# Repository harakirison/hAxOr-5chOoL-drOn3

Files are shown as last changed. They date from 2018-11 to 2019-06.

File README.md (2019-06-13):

# hAxOr-5chOoL-drOn3
Hacker School Drone 11/2018

ESP8266-12e als RX:

https://www.instructables.com/id/Wifi-PPM-no-App-Needed/

https://www.mikrocontroller-elektronik.de/esp12e-tutorial-einstieg-mit-dem-esp8266-modul/

### Propeller

* https://www.youtube.com/watch?v=CKGabWs2Ih0

### Useful-Links:
* https://www.youtube.com/watch?v=J66_8P043ko
* https://www.youtube.com/watch?v=8Dr_GhXI85I&t=0s
* https://www.youtube.com/watch?v=Mlgi6CB7WXQ
#### for flashing the FC:
* https://www.youtube.com/watch?v=Krv-CMSfb_M
* https://www.youtube.com/watch?v=cCgrKOVxnWQ
* https://www.youtube.com/watch?v=-fK6NnnAzuo

### Parts:

#### Flight Controller
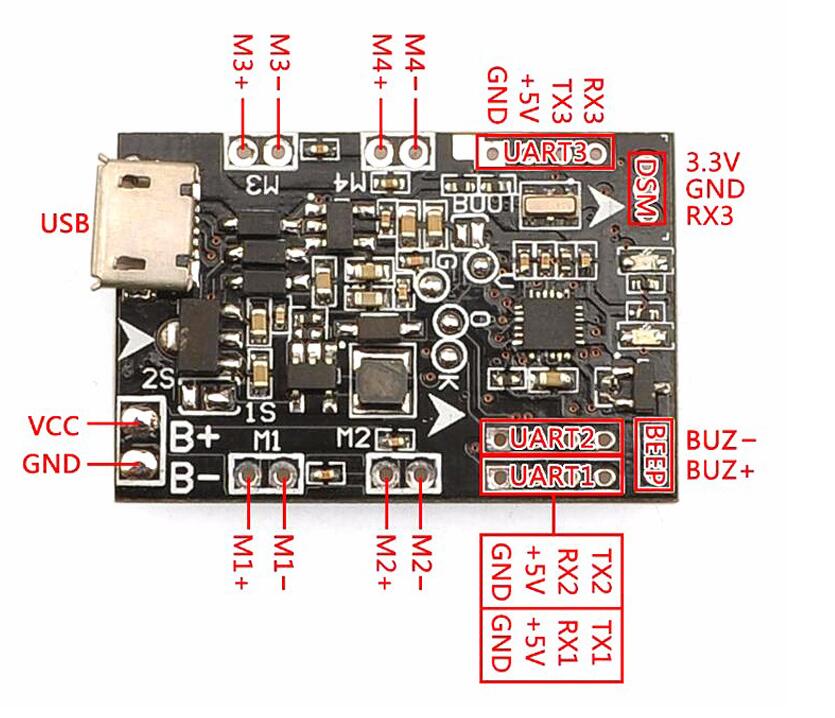
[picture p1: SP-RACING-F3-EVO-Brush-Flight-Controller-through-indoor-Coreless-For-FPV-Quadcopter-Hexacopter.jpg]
Flight Controller

* https://www.ebay.de/itm/F18730-SP-RACING-F3-EVO-Flugsteuerung-durch-Indoor-Coreless/152819911419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

#### Motors:
* https://de.aliexpress.com/item/10PCS-716-Coreless-Motor-Magnetic-Mini-HM-Motor-For-Helicopter-Airplane-Robotic/32793657274.html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
* https://de.aliexpress.com/item/10PCS-LOT-NdFeB-Super-Magnetic-8520-Hollow-Cup-Motor-3V-45000-RPM-Quadcopter-Model-Aircraft-Motor/32829046922.html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

#### Props:
* https://de.aliexpress.com/item/Accessories-For-Quadcopter-Propellers-Props-for-Eachine-E010-JJRC-H36-Blade-Inductrix-Tiny-Whoop-Drone-Part/32822191271.html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
* https://de.aliexpress.com/item/4-8-20-40-st-cke-49mm-4-9-cm-Requisiten-Mini-Propeller-Blades-Props-F/32922298325.html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
* https://de.aliexpress.com/item/Wholesale-65mm-Propeller-Prop-Blade-For-720-8520-Coreless-Motor-DIY-Micro-Quadcopter-spare-parts-40pcs/32799845267.html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
* https://de.aliexpress.com/item/40pcs-Mini-60mm-CW-CCW-Propeller-for-0720-0820-8520-Coreless-Motor-Hubsan-H107-Series-Q100/32779714494.html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

#### Camera
* https://de.aliexpress.com/item/LST-S2-5-8g-800TVL-HD-Micro-CMOS-FPV-Kamera-150-Grad-Winkel-Von-Ansicht-3/32856883661.html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

#### RX
* https://de.aliexpress.com/item/Free-Shipping-10pcs-lot-ESP8266-remote-serial-Port-WIFI-wireless-module-through-walls-Wang-ESP-12/1967135461.html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

### CLI Commands
set motor_pwm_rate = 32000

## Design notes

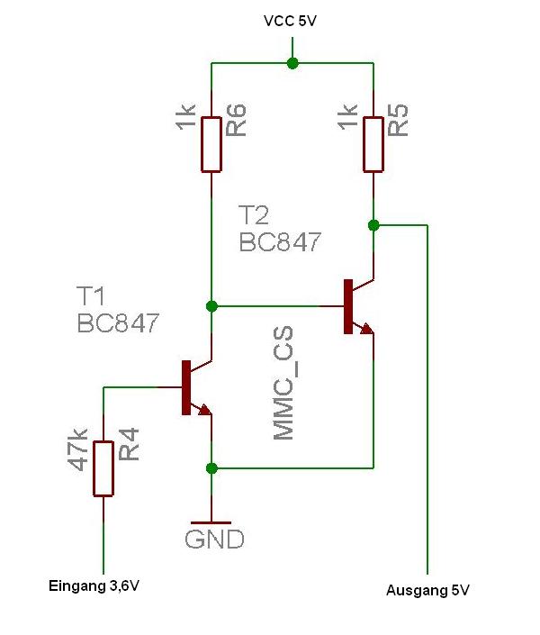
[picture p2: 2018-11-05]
Level_shifter_to_5v.JPG

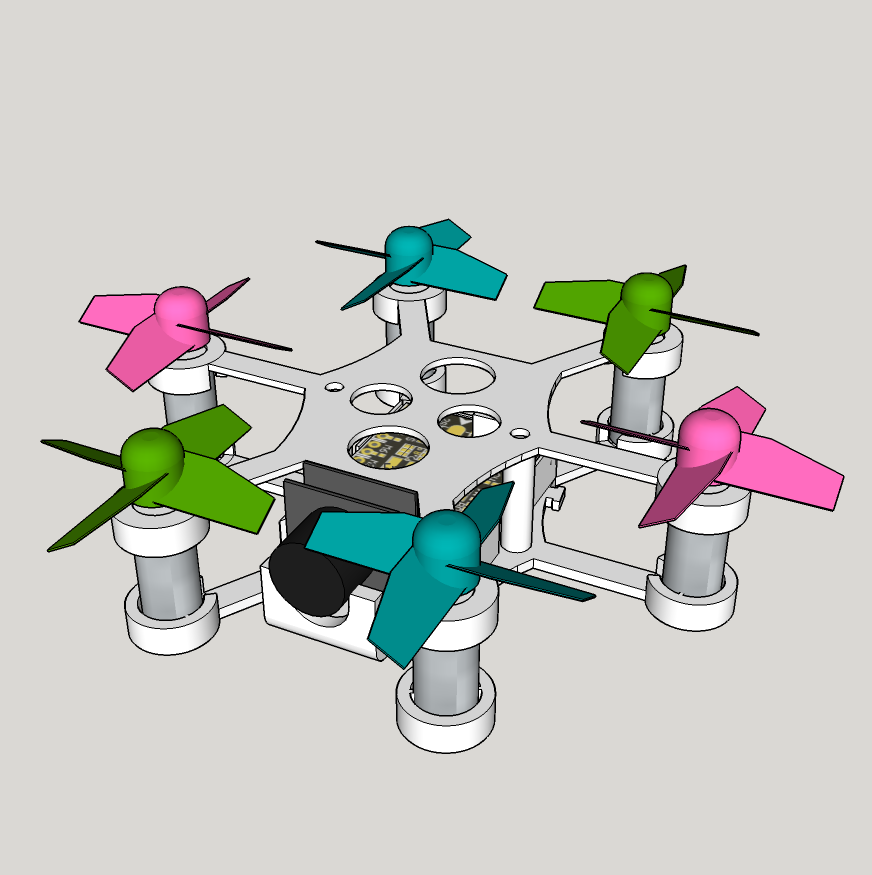
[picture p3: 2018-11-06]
drone_frame_716_hex.png

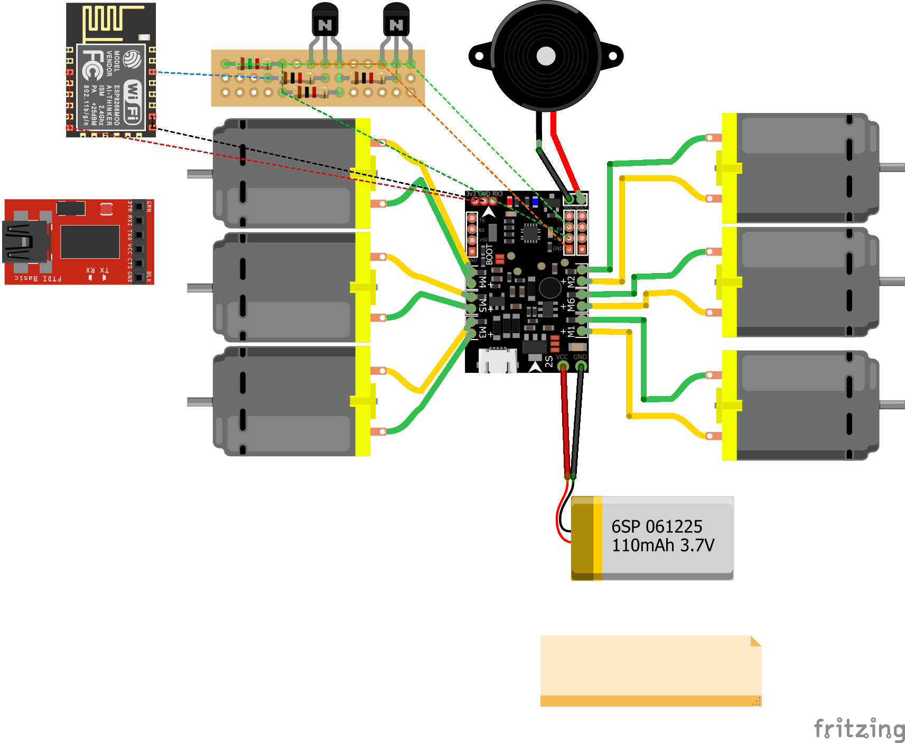
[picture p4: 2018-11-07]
drone_Steckplatine.png

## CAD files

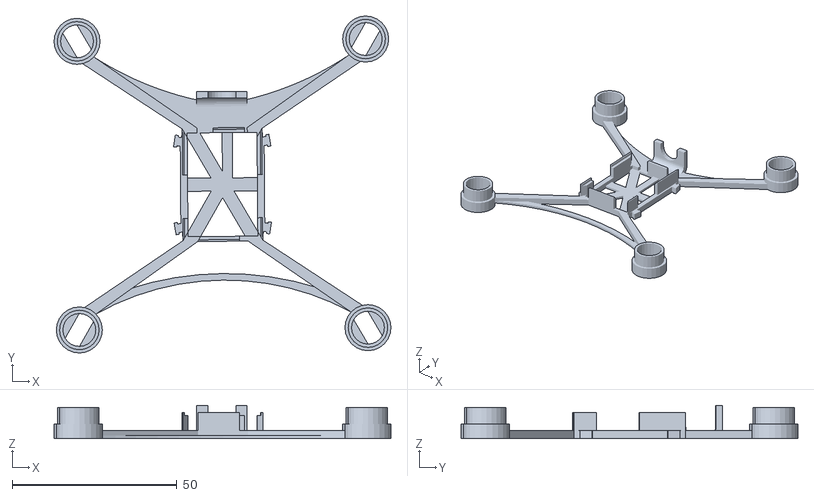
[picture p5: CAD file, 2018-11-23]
drone_frame_8520_quad.stl
102.4 x 102.4 x 10.1

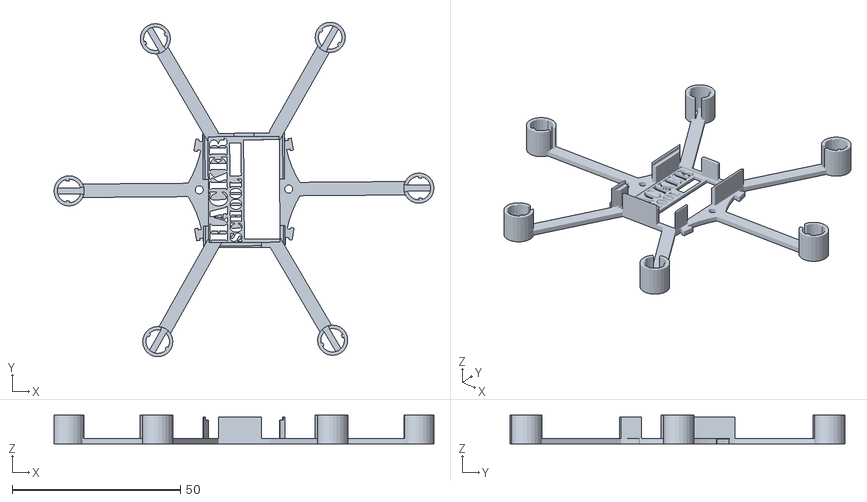
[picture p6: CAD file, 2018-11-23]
drone_frame_614_hex_49mm.stl
113.0 x 99.5 x 8.50

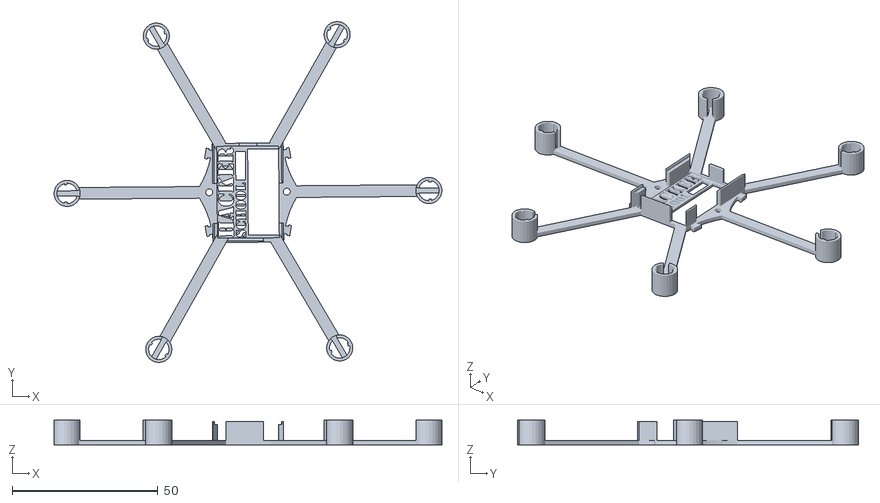
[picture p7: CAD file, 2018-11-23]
drone_frame_614_hex_60mm.stl
133.0 x 116.9 x 8.50

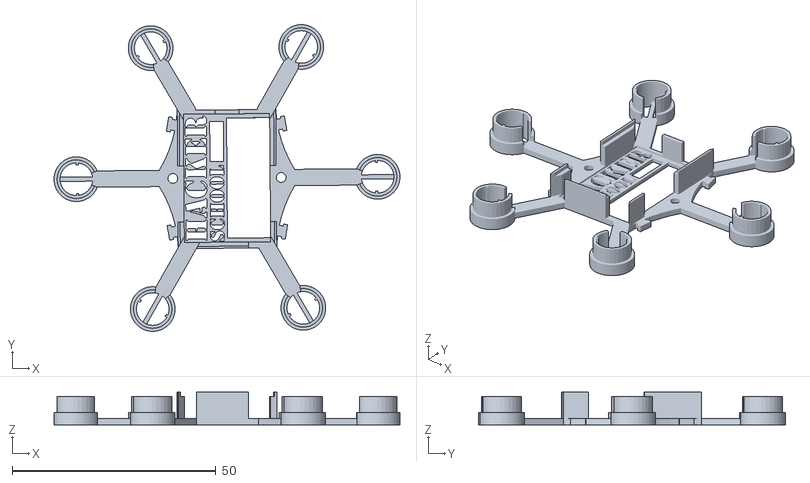
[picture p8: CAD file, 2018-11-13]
drone_frame_716_hex_simple.stl
85.0 x 75.4 x 8.00

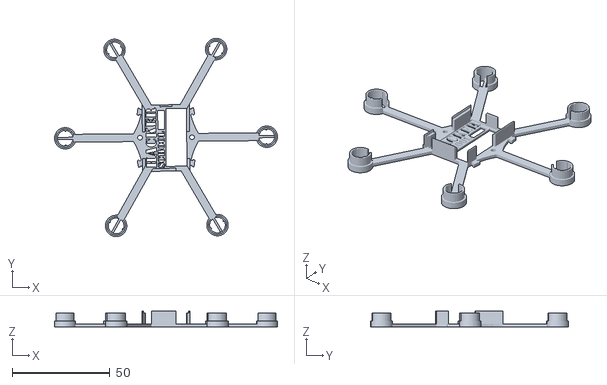
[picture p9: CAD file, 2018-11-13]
drone_frame_716_hex_50mm.stl
114.1 x 101.5 x 8.00

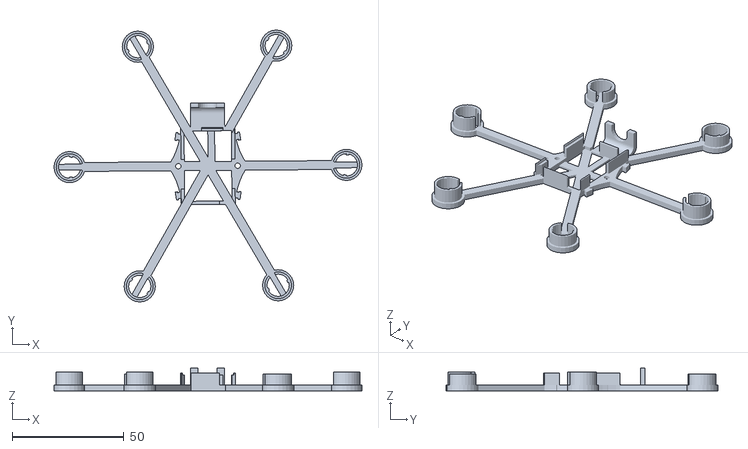
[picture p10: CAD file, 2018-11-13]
drone_frame_8520_hex_light.stl
138.0 x 121.9 x 10.1

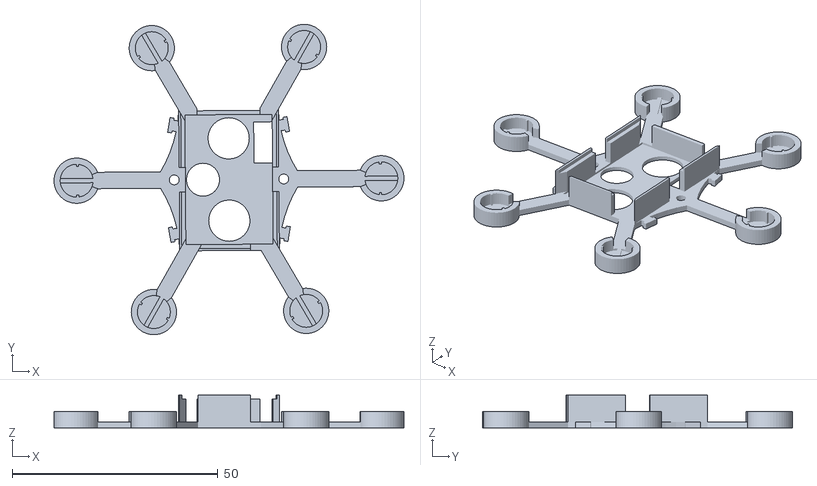
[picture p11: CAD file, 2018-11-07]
drone_frame_716_hex.stl
85.0 x 75.4 x 8.00

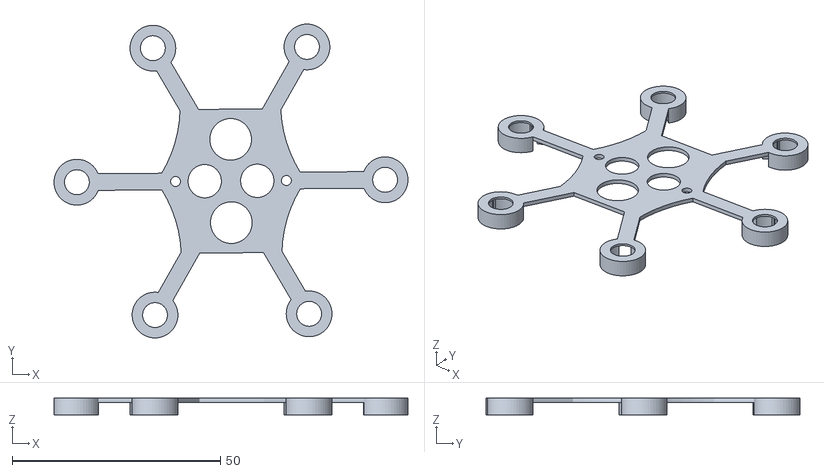
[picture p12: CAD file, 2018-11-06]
drone_frame_716_hex_top.stl
85.0 x 75.4 x 4.00

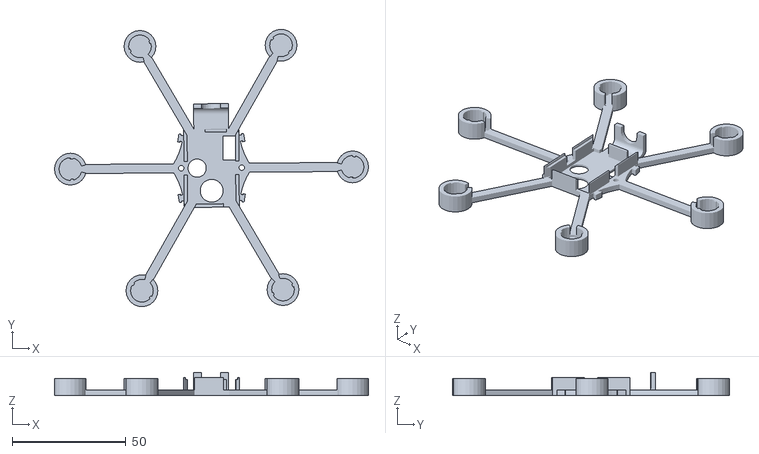
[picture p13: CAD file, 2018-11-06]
drone_frame_8520_hex.stl
138.0 x 121.9 x 10.1

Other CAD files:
drone_frame_716_hex.skp
drone_frame_8520_hex.skp
drone_frame_8520_quad.skp

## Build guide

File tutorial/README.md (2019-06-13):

# Programming ESP8266
## Schematic
ESP8266 Overview!

## Documentation
### Software
* [ESP8266 Wifi library](https://arduino-esp8266.readthedocs.io/en/latest/esp8266wifi/readme.html)
* [PID/Rate Settings](http://www.koptertreff.de/f21-tipps-amp-tutorials/t79-tutorial-rates-in-betaflight-einstellen)

### Hardware
* [F3 Evo Soldering](https://www.instructables.com/id/How-to-Solder-the-F3-EVO-Brushed-Flight-Controller/)

## Setting up Development Environment
* Download and install Arduino softwarefrom https://www.arduino.cc/en/Main/Software
* Add additional Boards Manager URL (File->Preferences->Settings): http://arduino.esp8266.com/stable/package_esp8266com_index.json
* Install Wifi Module (Tools -> Board -> Boards Manager): Search for "esp8266"
* Install WebSockets library (Tools -> Manage Library)
* Change Settings (Tools)
  * Baud: 115200 (921600 works as well but not as reliable as 115200)
  * Board: SparkFun ESP 8266 Thing
  * Port: dev/ttyUSB0 (or the corresponding COM port)

## Flashing the program
* Set ESP to flash mode by setting GPIO0 to GND
* Power on ESP
* Verify and upload program
  * [Blinky](https://github.com/harakirison/hAxOr-5chOoL-drOn3/tree/master/src/blinky) (test program with flashing led light)
  * [Drone HTML5 controller](https://github.com/harakirison/hAxOr-5chOoL-drOn3/tree/master/src/wifippm)

## Settings in BetaFlight
* Go to Receiver settings and make the following changes 
  * Channel Map value: RTAE1234
  * Stick Low Threshold: 1020
  * Stick Center: 1496
  * Stick High Threshold: 1980
  * RC Deadband: 5
  * Yaw Deadband: 5
* Go to Mode settings and make the following changes
  * ARM / Aux 1 / 1600-2000
  * ANGLE / Aux 2 / 900-1300
  * HORIZON / Aux 2 / 1600-2000
* Go to PID Tuning and make the following changes
  * RC Rate: 0,40 (Roll, Pitch, Yaw)
  * Super Rate: 0,20 (Roll, Pitch, Yaw)
  * RC Expo: 0,70 (Roll, Pitch, Yaw)
* Go to Configuration and make the following changes
  * Enable MOTOR_STOP

## CLI
set motor_pwm_rate = 32000

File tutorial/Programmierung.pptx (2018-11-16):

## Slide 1

ESP8266-12e

Webserver
(Frontend)

WebSocket Server
(Backend)

Wireless LAN
Access-Point

Motor

Motor

Motor

Motor

Motor

Motor

F18730 SP Racing F3 EVO

Flight Controller

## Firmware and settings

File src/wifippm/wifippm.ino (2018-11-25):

/*
   Small webserver with HTML5 interface that creates PPM signals for flight controller.
   Original source: https://www.instructables.com/id/Wifi-PPM-no-App-Needed/

   Modified and optimized for hAxOr-5chOoL-drOn3
*/

#include <ESP8266WiFi.h>
#include <ESP8266WebServer.h>
#include <WebSocketsServer.h>

#define CPU_MHZ 80
#define CHANNEL_NUMBER 8  //set the number of chanels
#define FRAME_LENGTH 22500  //set the PPM frame length in microseconds (1ms = 1000µs)
#define PULSE_LENGTH 300  //set the pulse length
#define ON_STATE 0  //set polarity of the pulses: 1 is positive, 0 is negative
#define SIG_PIN 5 //set PPM signal output pin on the arduino
#define AP_MODE 1 //set to WIFI Access Point or Client mode

/* Set these to your desired credentials. */
const char *ssid = "WifiPPM";
const char *password = "Wifi_PPM";

/* PPM[0]=Yaw, PPM[1}=Throttle, PPM[2]=Roll, PPM[3]=Pitch, PPM[4]=Button1, PPM[5]=Button2, PPM[5]=Button3, PPM[5]=Button4 */
int ppm[CHANNEL_NUMBER];

volatile unsigned long next;
volatile unsigned int ppm_running = 1;
unsigned int alivecount = 0;

extern const char index_html[];

ESP8266WebServer server (80);
WebSocketsServer webSocket = WebSocketsServer(81);

/**
   @brief Send PPM signal
*/
void inline ppmISR() {
  static boolean state = true;

  if (state) {  //start pulse
    digitalWrite(SIG_PIN, ON_STATE);
    next = next + (PULSE_LENGTH * CPU_MHZ);
    state = false;
    alivecount++;
  }
  else { //end pulse and calculate when to start the next pulse
    static byte cur_chan_numb;
    static unsigned int calc_rest;

    digitalWrite(SIG_PIN, !ON_STATE);
    state = true;

    if (cur_chan_numb >= CHANNEL_NUMBER) {
      cur_chan_numb = 0;
      calc_rest = calc_rest + PULSE_LENGTH;//
      next = next + ((FRAME_LENGTH - calc_rest) * CPU_MHZ);
      calc_rest = 0;
    }
    else {
      next = next + ((ppm[cur_chan_numb] - PULSE_LENGTH) * CPU_MHZ);
      calc_rest = calc_rest + ppm[cur_chan_numb];
      cur_chan_numb++;
    }
  }
  timer0_write(next);
}

/**
   @brief Sets PPM output to default value
*/
void inline resetPPM() {
  ppm[0] = 1500; ppm[1] = 1100; ppm[2] = 1500; ppm[3] = 1500;
  ppm[4] = 1100; ppm[5] = 1100; ppm[6] = 1100; ppm[7] = 1100;
}

/**
    @brief Handle webserver call of root element
*/
void handleRoot() {
  if (ppm_running == 0) {
    noInterrupts();
    timer0_isr_init();
    timer0_attachInterrupt(ppmISR);
    next = ESP.getCycleCount() + 1000;
    timer0_write(next);
    resetPPM();
    ppm_running = 1;
    interrupts();
  }
  server.send_P(200, "text/html", index_html);
}

/**
   @brief Handle WebSocket events

   @param num
   @param type
   @param payload
   @param length
*/
void webSocketEvent(uint8_t num, WStype_t type, uint8_t * payload, size_t length) {
  switch (type) {
    case WStype_DISCONNECTED: {
        resetPPM();
        Serial.println("Connection to WebSocket closed...");
      }
      break;
    case WStype_CONNECTED: {
        // send message to client
        webSocket.sendTXT(num, "Connected");
        resetPPM();
        Serial.println("Connection to WebSocket established...");
      }
      break;
    case WStype_BIN: {
        ppm[payload[0]] = (payload[1] << 8) + payload[2];
        alivecount = 0;
      }
      break;
  }
}

/**
   @brief Setup WIFI either with Access-Point mode or Client mode.

   Mode depends on directive AP_MODE:
    1 = Access-Point mode
    0 = Client mode
*/
void inline setupWiFi() {
  if (AP_MODE) {
    WiFi.softAP(ssid, password, 2);
    return;
  }

  WiFi.begin(ssid, password);
  Serial.print("Connecting to WiFi");

  while (WiFi.status() != WL_CONNECTED) {
    delay(500);
    Serial.print(".");
  }
  Serial.println();
  Serial.print("Connected with IP: ");
  Serial.println(WiFi.localIP());
}

/**
   @brief Main setup
*/
void setup() {
  // Setup serial port
  Serial.begin(115200);

  // Setup PPM output pin and set the PPM signal
  // pin to the default state (off)
  pinMode(SIG_PIN, OUTPUT);
  digitalWrite(SIG_PIN, !ON_STATE);

  // Setup WIFI (AP or Client mode)
  setupWiFi();

  // Setup HTTP webserver and register handlers
  server.on("/", handleRoot);
  server.begin();

  // Setup WebSocket server
  webSocket.onEvent(webSocketEvent);
  webSocket.begin();

  noInterrupts();
  timer0_isr_init();
  timer0_attachInterrupt(ppmISR);
  next = ESP.getCycleCount() + 1000;
  timer0_write(next);
  resetPPM();
  interrupts();
}

/**
   @brief Main loop
*/
void loop() {
  webSocket.loop();
  server.handleClient();

  if (alivecount > 1000) {
    resetPPM();
  }
  yield();
}

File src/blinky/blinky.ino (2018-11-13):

/*
 ESP12E-Test
 Led an dem ESP8266 Modul Typ ESP12E blinken lassen
 und Zahlenfolge über serielle Schnittstelle ausgeben

 Programm erprobt ab Arduino IDE 1.8.7
 Weitere Beispiele unter https://www.mikrocontroller-elektronik.de/
*/

#include <ESP8266WiFi.h>


#define LED 2 //GPIO2 - Led auf dem Modul selbst

int i;

void setup() {
 pinMode(LED, OUTPUT); // Port aus Ausgang schalten

 Serial.begin(115200);
 delay(10);
 
 Serial.println("");
 Serial.println("ESP12E Modul Test"); 
}


void loop() {
 
 digitalWrite(LED, LOW); //Led port ausschalten
 delay(1000); //1 Sek Pause
 digitalWrite(LED, HIGH); //Led port einschlaten
 delay(1000); 
 
 Serial.println(i); 
 i++;
}

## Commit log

2018-11-06 3d files
    [drone_frame_716_hex.skp, drone_frame_716_hex_top.stl, drone_frame_8520_hex.skp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]
2018-11-07 716 Motor ohne Cam
    [drone_frame_716_hex.stl]
2018-11-07 add fritzing files
    [drone.fzz]
2018-11-13 Some improv. Frames
    [drone_frame_716_hex_50mm.stl, drone_frame_716_hex_simple.stl, drone_frame_8520_hex.skp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]
2018-11-13 Added directive for switching between AP and client mode
2018-11-18 Corrected default PPM values
    [wifippm.ino]
2018-11-18 Cleaned up some code and corrected default setting for yaw
    [wifippm.ino]
2018-11-23 new 3d designs
    [drone_frame_614_hex_49mm.stl, drone_frame_614_hex_60mm.stl, drone_frame_8520_quad.skp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]
2018-11-24 Bugfixes in HTML5 frontend Small changes in ESP implementation
    [wifippm.ino]
